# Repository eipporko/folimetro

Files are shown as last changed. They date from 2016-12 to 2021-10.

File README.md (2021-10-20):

"Buy Me A Coffee" (https://www.buymeacoffee.com/eipporko)

# Folimetro

Folimetro is able to measure the air pressure into a galician bagpipe, connecting it instead of the ronqueta drone.

## Motivation

One of the most tricky things to do when playing the bagpipe is maintaining the level of the air pressure in the bag, in order to keep the sound of the drones.

The idea behind this project was to give support to the students and teachers of this instrument to control this problem.

## How it works?

This device consist of 9 leds who marks the pressure and 2 push buttons to displace the pressure value of the central led.

```
                                          PRESSURE VALUE (kPA)
          0.2  0.8  1.4  2.0  2.6  3.2  3.8  4.4  5.0  5.6  6.2  6.8  7.4  8.0  8.6  9.2  9.8
                               |    |    |    |    |    |    |    |    |    
                              -4   -3   -2   -1    0    1    2    3    4  
                                            NUMBER OF LED

```

## Project structure
* `docs` - various PDF datasheets for component used.
* `hardware` - Fritzing Schematic.
* `folimetro.ino` - Arduino project.

## Hardware Requirements

* Arduino Micro Pro (Leonardo)
* 11x Leds
* 10x 1k Ohm resistor
* 2x Push button
* 2x 10k Ohm resistor
* Pressure sensor (0 to 10kPA)

## Arduino Schematic
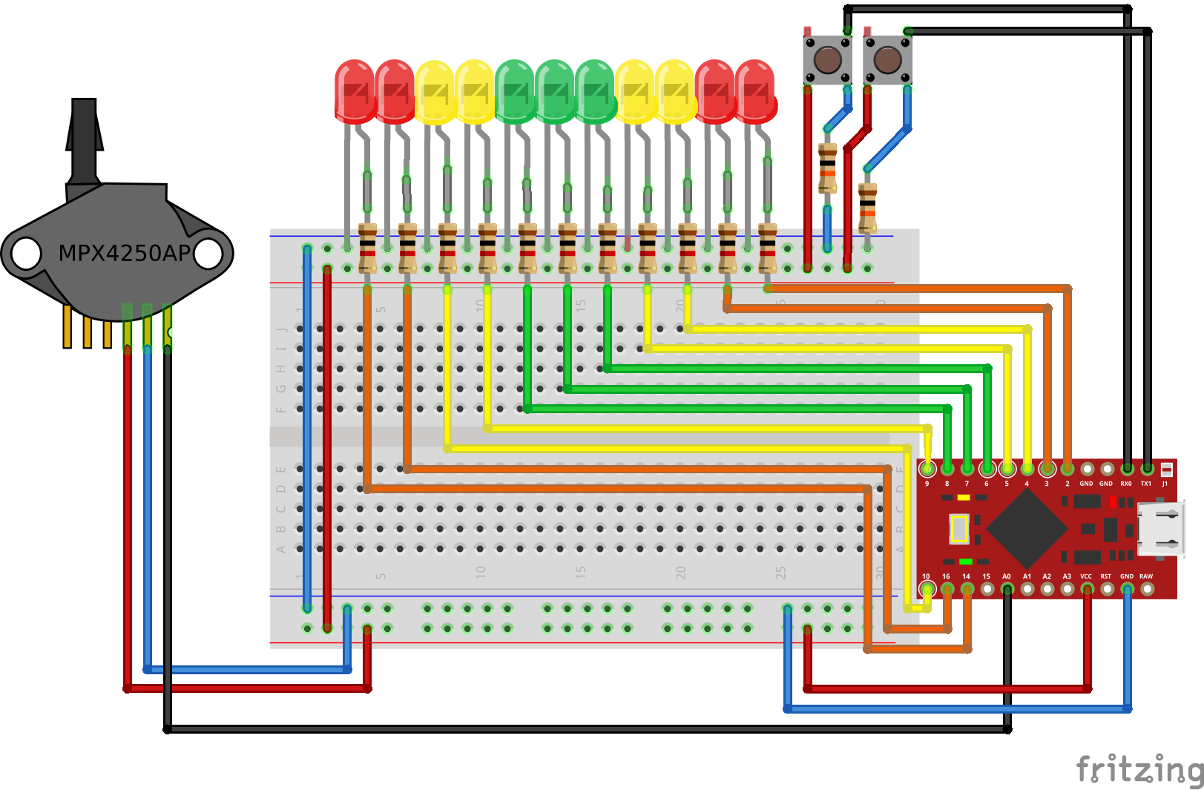
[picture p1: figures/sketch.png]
Connection Scheme


## Reference
1.  Cassandre Balosso-Bardin, Camille Vauthrin, Patricio de la Cuadra, Ilya Franciosi, Khalil Ben Mansour, Lise Ochej. EuroRegio2016 (2016, June 13-15). *\<\<The musical arm of the bagpipe player: a cultural and mechanical approach>>*  [[Link]]( http://www.sea-acustica.es/fileadmin/Oporto16/73.pdf)

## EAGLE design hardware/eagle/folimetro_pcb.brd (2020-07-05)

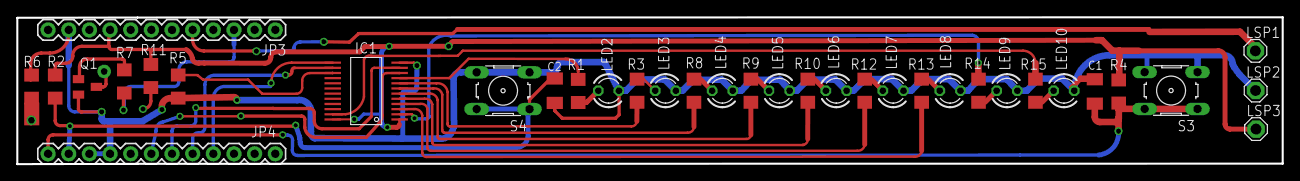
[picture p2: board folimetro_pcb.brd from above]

Board: 2 copper layers, 155.6 x 18.1 mm, 35 parts (0 on the bottom side), 30 nets.

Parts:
C1, C2: C1206K
IC1: SO24W
JP3, JP4: 1X12
LED2, LED3, LED4, LED5, LED6, LED7, LED8, LED9, LED10: LED3MM
LSP1, LSP2, LSP3: SE13
Q1: BC547; SOT23
R1, R2, R3, R4, R5, R6, R7, R8, R9, R10, R11, R12, R13, R14, R15: R1206
S3, S4: B3F-10XX

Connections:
+5V: IC1.1, IC1.24, JP3.4, LSP3.MP, R2.1, R4.2, R11.2
GND: C1.2, C2.2, IC1.12, JP3.2, JP4.9, JP4.10, LED2.K, LED3.K, LED4.K, LED5.K, LED6.K, LED7.K, LED8.K, LED9.K, LED10.K, LSP2.MP, Q1.2, R5.1, R6.1, S3.3, S3.4, S4.3, S4.4
unnamed: C1.1, JP4.12, R4.1, S3.1, S3.2
unnamed: Q1.1, R7.2
unnamed: IC1.15, R5.2
unnamed: IC1.10, JP4.7
unnamed: IC1.11, JP4.6
unnamed: IC1.14, JP4.5
unnamed: IC1.13, JP4.4
unnamed: IC1.9, R1.2
unnamed: LED2.A, R1.1
unnamed: IC1.8, R3.2
unnamed: LED3.A, R3.1
unnamed: IC1.2, R14.2
unnamed: IC1.7, R8.2
unnamed: LED4.A, R8.1
unnamed: IC1.6, R9.2
unnamed: LED5.A, R9.1
unnamed: IC1.5, R10.2
unnamed: LED6.A, R10.1
unnamed: IC1.4, R12.2
unnamed: LED7.A, R12.1
unnamed: IC1.3, R13.2
unnamed: LED8.A, R13.1
unnamed: IC1.23, R15.2
unnamed: LED9.A, R14.1
unnamed: C2.1, JP4.11, R2.2, S4.1, S4.2
unnamed: LED10.A, R15.1
unnamed: JP3.10, R7.1
unnamed: JP3.8, LSP1.MP

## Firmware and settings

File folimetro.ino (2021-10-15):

/*

   FOLIMETRO

   Copyright (c) David Antunez Gonzalez 2016 <dantunezglez@gmail.com>

   All rights reserved.

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
*/
//For Arduino Pro Micro
#include <SoftwareSerial.h>

#define DEBOUNCE_TIME          150
#define NUM_OF_LEDS            9
#define CONFIRM_DURATION       300
#define BLINK_DELAY            200
#define TIMEOUT                1000

//Pins
#define BLUETOOTH_ENABLE_PIN   14
#define BLUETOOTH_TX_PIN       10
#define BLUETOOTH_RX_PIN       16
#define BLUETOOTH_S_WINDOW     25

#define BUTTON_DOWN_PIN        0 
#define BUTTON_UP_PIN          1

#define PIN_A                  3
#define PIN_B                  4
#define PIN_C                  5
#define PIN_D                  6

#define SENSOR_PIN             A0

SoftwareSerial btSerial(BLUETOOTH_TX_PIN, BLUETOOTH_RX_PIN);

const int controlPin[4] = {PIN_A, PIN_B, PIN_C, PIN_D}; // 4 pins used  for binary output antes (3,4,5,6)
const int muxTable[NUM_OF_LEDS+1][4] = {
  // s0, s1, s2, s3     channel
  {0,  0,  0,  0}, // 0
  {1,  0,  0,  0}, // 1
  {0,  1,  0,  0}, // 2
  {1,  1,  0,  0}, // 3
  {0,  0,  1,  0}, // 4
  {1,  0,  1,  0}, // 5
  {0,  1,  1,  0}, // 6
  {1,  1,  1,  0}, // 7
  {0,  0,  0,  1}, // 8
  {1,  0,  0,  1}, // 9
};

volatile bool decreaseButtonPressed = false;
volatile byte level = 4;
volatile unsigned long lastInterruptTime = 0;

typedef enum ProgramState {MAIN_STATE, CHANGE_LEVEL_STATE} ProgramState_t;
ProgramState_t stateProgram = MAIN_STATE;


void increaseLevel() {
  static unsigned long lastTime = 0;
  unsigned long now = millis();
  lastInterruptTime = now;

  if (now - lastTime > DEBOUNCE_TIME) {
   
    if (stateProgram != CHANGE_LEVEL_STATE) {
      changeStateProgram(CHANGE_LEVEL_STATE);
      return;
    }
    
    if (level < NUM_OF_LEDS-1) {
      level += 1;
    }

    lastTime = now;
  }
}


void decreaseLevel() {

  if (!decreaseButtonPressed) {
  static unsigned long lastTime = 0;
  unsigned long now = millis();

  lastInterruptTime = now;

  if (now - lastTime > DEBOUNCE_TIME) {

    if (stateProgram != CHANGE_LEVEL_STATE) {
      changeStateProgram(CHANGE_LEVEL_STATE);
      return;
    }
  
    if (level > 0) {
     level -= 1;
    }
     
    lastTime = now;
   }
  }
}


void blinkAllLedsAnimation() {
  for (int i = 0; i < 2; i++) {
    unsigned long timeToReach = millis() + 150;
    while (millis() < timeToReach) {
      for (int j = 0; j < NUM_OF_LEDS; j++) {
       turnOnLed(j);
      }
    }
    turnOffLeds();
    delay (150);
  }
}


void enableBluetoothAnimation() {
  byte middleLed = 4;
  byte animation_steps = 5;
  byte num_of_leds = 0;
  for (byte i = 0; i < animation_steps; i++) {
    unsigned long timeToReach = millis() + CONFIRM_DURATION/(animation_steps-1);
    num_of_leds++;
    while (millis() < timeToReach) {
      for (int j = 0; j < num_of_leds; j++) {
        turnOnLed(middleLed + j);
        delay(2);
        turnOnLed(middleLed - j);
        delay(2);
       }
    }
  }
  blinkAllLedsAnimation();
}


void disableBluetoothAnimation() {  
  byte middleLed = 4;
  byte animation_steps = 5;
  byte num_of_leds = 6;
  blinkAllLedsAnimation();
  for (byte i = 0; i < animation_steps; i++) {
    unsigned long timeToReach = millis() + CONFIRM_DURATION/(animation_steps-1);
    num_of_leds--;
    while (millis() < timeToReach) {
      for (int j = 0; j < num_of_leds; j++) {
        turnOnLed(middleLed + j);
        delay(2);
        turnOnLed(middleLed - j);
        delay(2);
       }
    }
  }
}


void turnOnLed(int numOfLed)
{
  if (numOfLed < 0) {
    turnOnLed(0);
  }
  else if (numOfLed >= NUM_OF_LEDS) {
    turnOnLed(NUM_OF_LEDS - 1);
  }
  else {
    digitalWrite(controlPin[0], muxTable[numOfLed][0]);
    digitalWrite(controlPin[1], muxTable[numOfLed][1]);
    digitalWrite(controlPin[2], muxTable[numOfLed][2]);
    digitalWrite(controlPin[3], muxTable[numOfLed][3]);
  }
}


void turnOffLeds() {
  digitalWrite(controlPin[0], 0);
  digitalWrite(controlPin[1], 0);
  digitalWrite(controlPin[2], 1);
  digitalWrite(controlPin[3], 1);
}

void changeStateProgram(ProgramState_t newState) {
  stateProgram = newState;
  turnOffLeds();
}


void mainState() {
  short pressure = analogRead(SENSOR_PIN); 
  byte ledIndex = map(pressure, 0, 1023, 0, (NUM_OF_LEDS-1)*2);
  turnOnLed(ledIndex - level);
  
  btSerial.println(pressure +'\n');
  delay(BLUETOOTH_S_WINDOW);
  
  if (stateProgram != MAIN_STATE)
    turnOffLeds();
}


void changeLevelState() {
  turnOnLed(level);
  delay(BLINK_DELAY);
  turnOffLeds();
  delay(BLINK_DELAY);

  if (millis() - lastInterruptTime > TIMEOUT){
    changeStateProgram(MAIN_STATE);
  }

  if (stateProgram != CHANGE_LEVEL_STATE)
    turnOffLeds();
}


void setup() {
  pinMode(BUTTON_DOWN_PIN, INPUT_PULLUP);
  pinMode (BUTTON_UP_PIN, INPUT_PULLUP);
  pinMode (BLUETOOTH_ENABLE_PIN, OUTPUT);
  pinMode(BUTTON_UP_PIN, INPUT);
  pinMode(BUTTON_DOWN_PIN, INPUT);

  digitalWrite(BLUETOOTH_ENABLE_PIN, LOW);
  
  btSerial.begin(9600);
  Serial.begin(9600);
  
  attachInterrupt(digitalPinToInterrupt(BUTTON_UP_PIN), increaseLevel, RISING);
  attachInterrupt(digitalPinToInterrupt(BUTTON_DOWN_PIN), decreaseLevel, RISING);

  for (int i = 0; i < 4; i++)
  {
    pinMode(controlPin[i], OUTPUT);//  establece pin como salida
  }
}


void toggleBluetooth() {
  bool blEnabled = digitalRead(BLUETOOTH_ENABLE_PIN);
  if (blEnabled) {
    digitalWrite(BLUETOOTH_ENABLE_PIN, LOW);
    disableBluetoothAnimation();
  }
  else {
    digitalWrite(BLUETOOTH_ENABLE_PIN, HIGH);
    enableBluetoothAnimation();
  }
}


void loop() {
  unsigned long timePressed = 0;

  //Check if the Decrease Button is Pressed in a long way in
  //order to enable/disable bluetooth dongle
  if (digitalRead(BUTTON_DOWN_PIN) == LOW) {
    unsigned long now = millis();
    while (digitalRead(BUTTON_DOWN_PIN) == LOW) {
      if (millis() - now > 500) {
        decreaseButtonPressed = true;
        toggleBluetooth();
        break;
      }
    }
    decreaseButtonPressed = false;
  }
  
  switch (stateProgram) {
    case MAIN_STATE:
      mainState();
      break;
    case CHANGE_LEVEL_STATE:
      changeLevelState();
    default:
      break;
  }
}

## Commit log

2016-12-18 Foliometro v1.0
    [sketch.fzz]
2016-12-19 Updated fritzing sketch
    [sketch.fzz]
2020-07-04 Adapting the firmware to the pcb developed by my father
2020-07-05 Establishing a delay of 25 ms to send the pressure information throw Bluetooth.
    [folimetro_pcb.brd, folimetro_pcb.sch]
